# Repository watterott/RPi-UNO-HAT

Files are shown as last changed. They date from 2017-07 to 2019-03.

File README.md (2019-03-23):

# RPi-UNO-HAT
Raspberry Pi to Arduino/Genuino Shield Bridge.

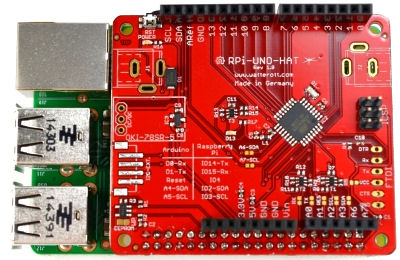
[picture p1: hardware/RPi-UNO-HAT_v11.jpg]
RPi-UNO-HAT


* Microchip ATmega328P with Arduino compatible Bootloader (optiboot)
* Raspberry Pi connected via I2C and UART (to the AVR through level-shifter)
* AVR-Programming via Raspberry Pi possible
* [Raspberry Pi HAT](https://github.com/raspberrypi/hats) compatible (40 pin connector)
* Shield connectors with Uno R3 layout
* Additional 3.3V LDO voltage regulator for Shields
* Optional 7-36V power input for Raspberry Pi and RPi-UNO-HAT (Murata OKI-78SR-5)
* Open-Source and released under the [Creative Commons Attribution Share-Alike License](https://creativecommons.org/licenses/by-sa/4.0/).
* **[Documentation on learn.watterott.com](https://learn.watterott.com)**

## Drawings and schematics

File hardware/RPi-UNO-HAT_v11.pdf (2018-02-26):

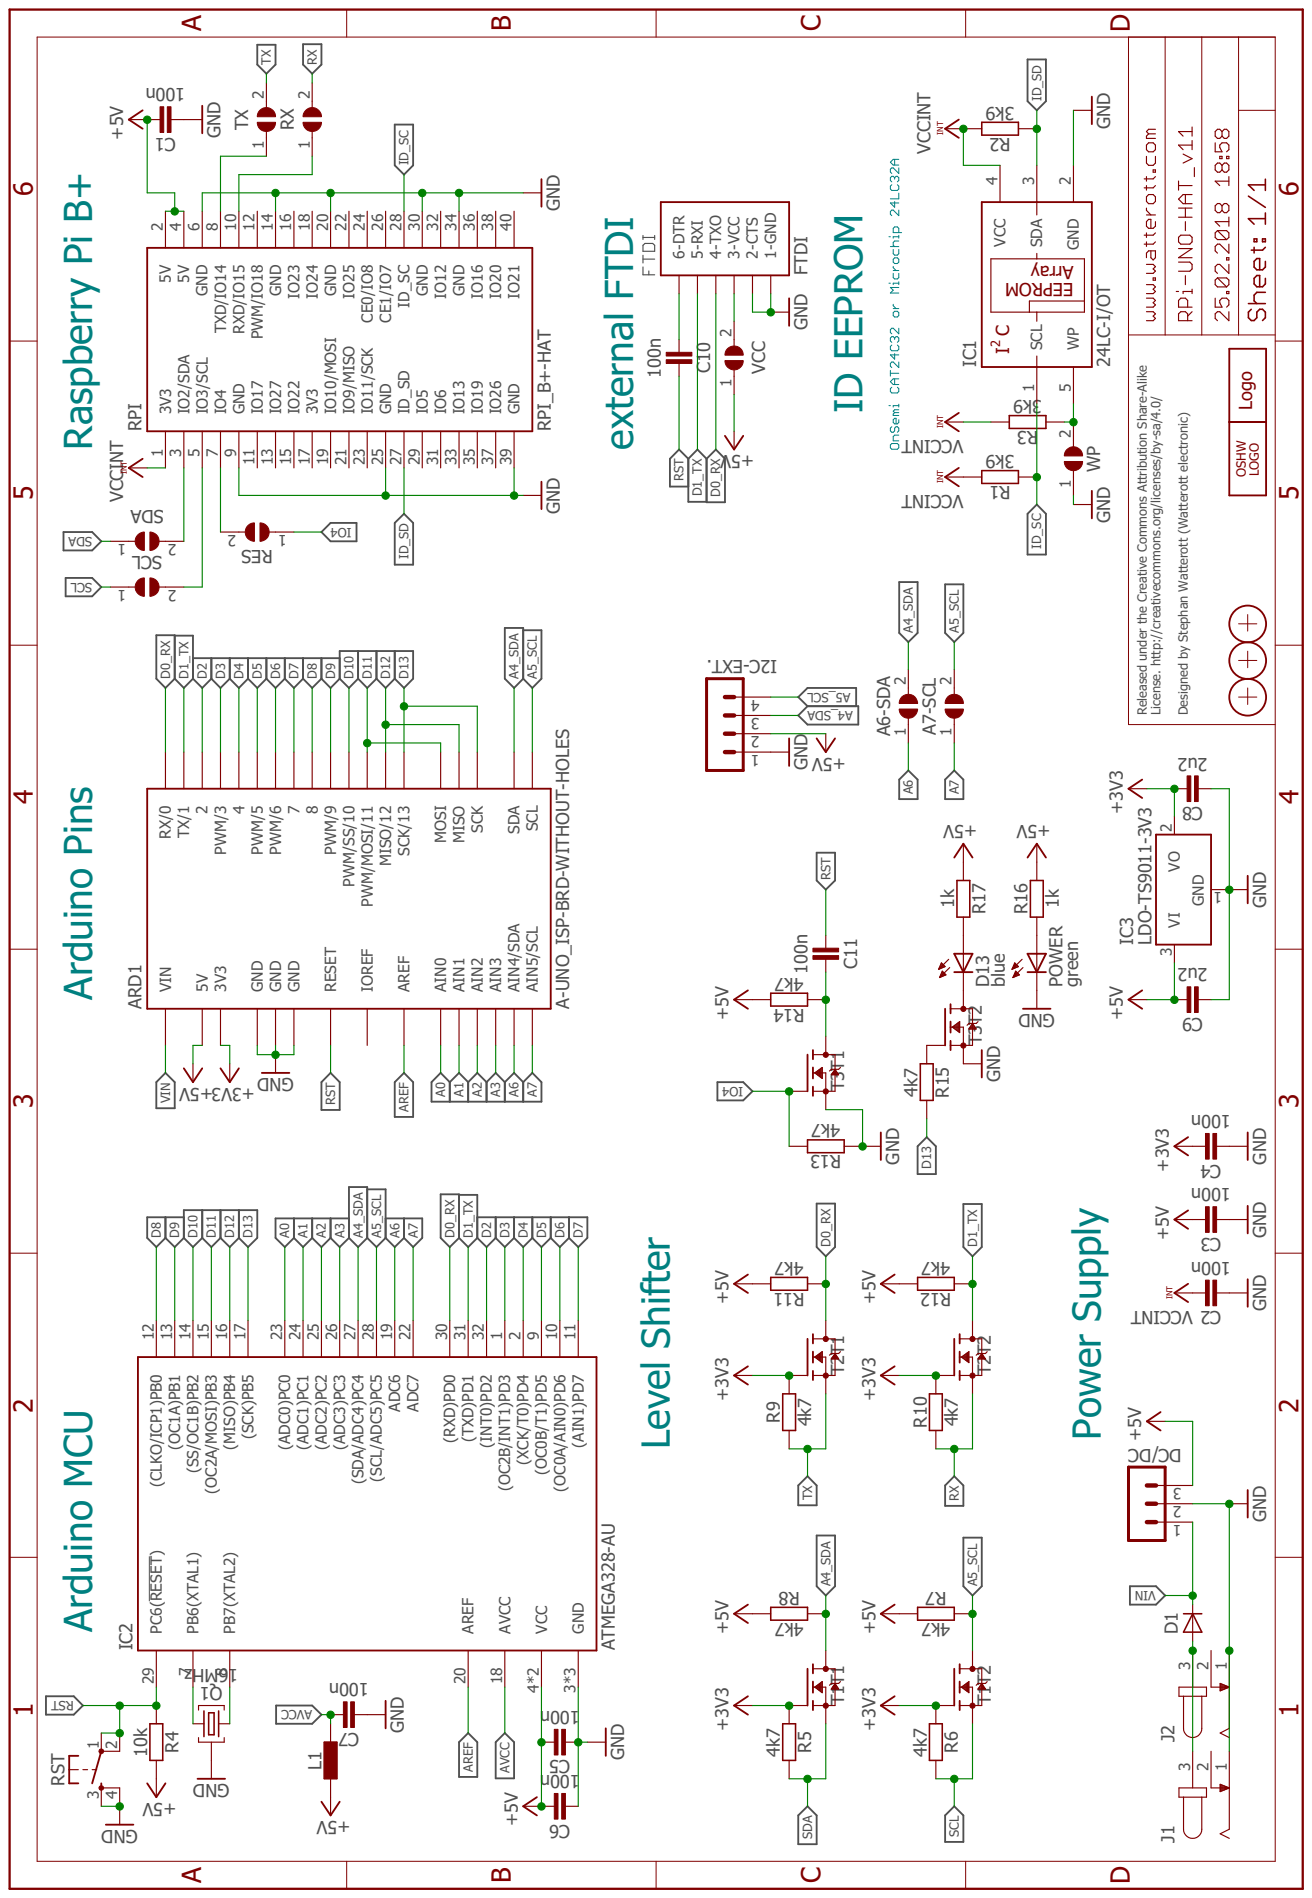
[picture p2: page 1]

Released under the Creative Commons Attribution Share-Alike

License. http://creativecommons.org/licenses/by-sa/4.0/ Designed by Stephan Watterott (Watterott electronic)

8 PWM/9 PWM/SS/10 PWM/MOSI/11 MISO/12 SCK/13 AIN1 AIN2 AIN3 AIN4/SDA

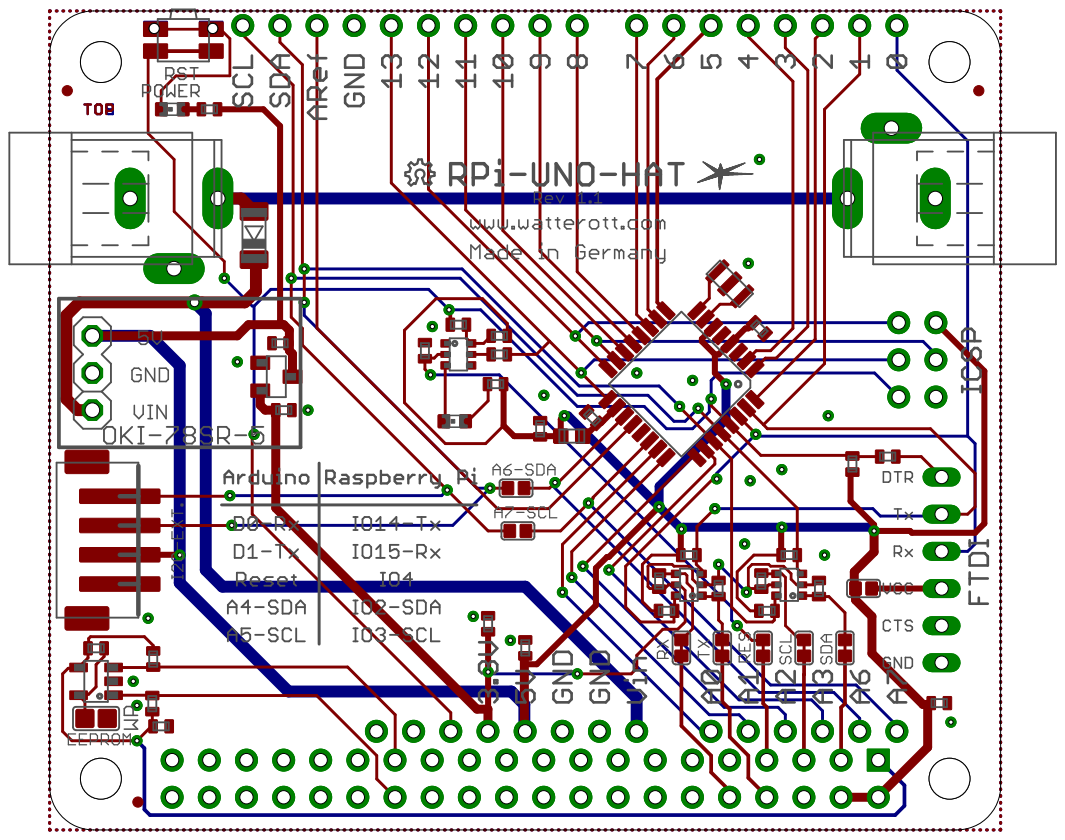
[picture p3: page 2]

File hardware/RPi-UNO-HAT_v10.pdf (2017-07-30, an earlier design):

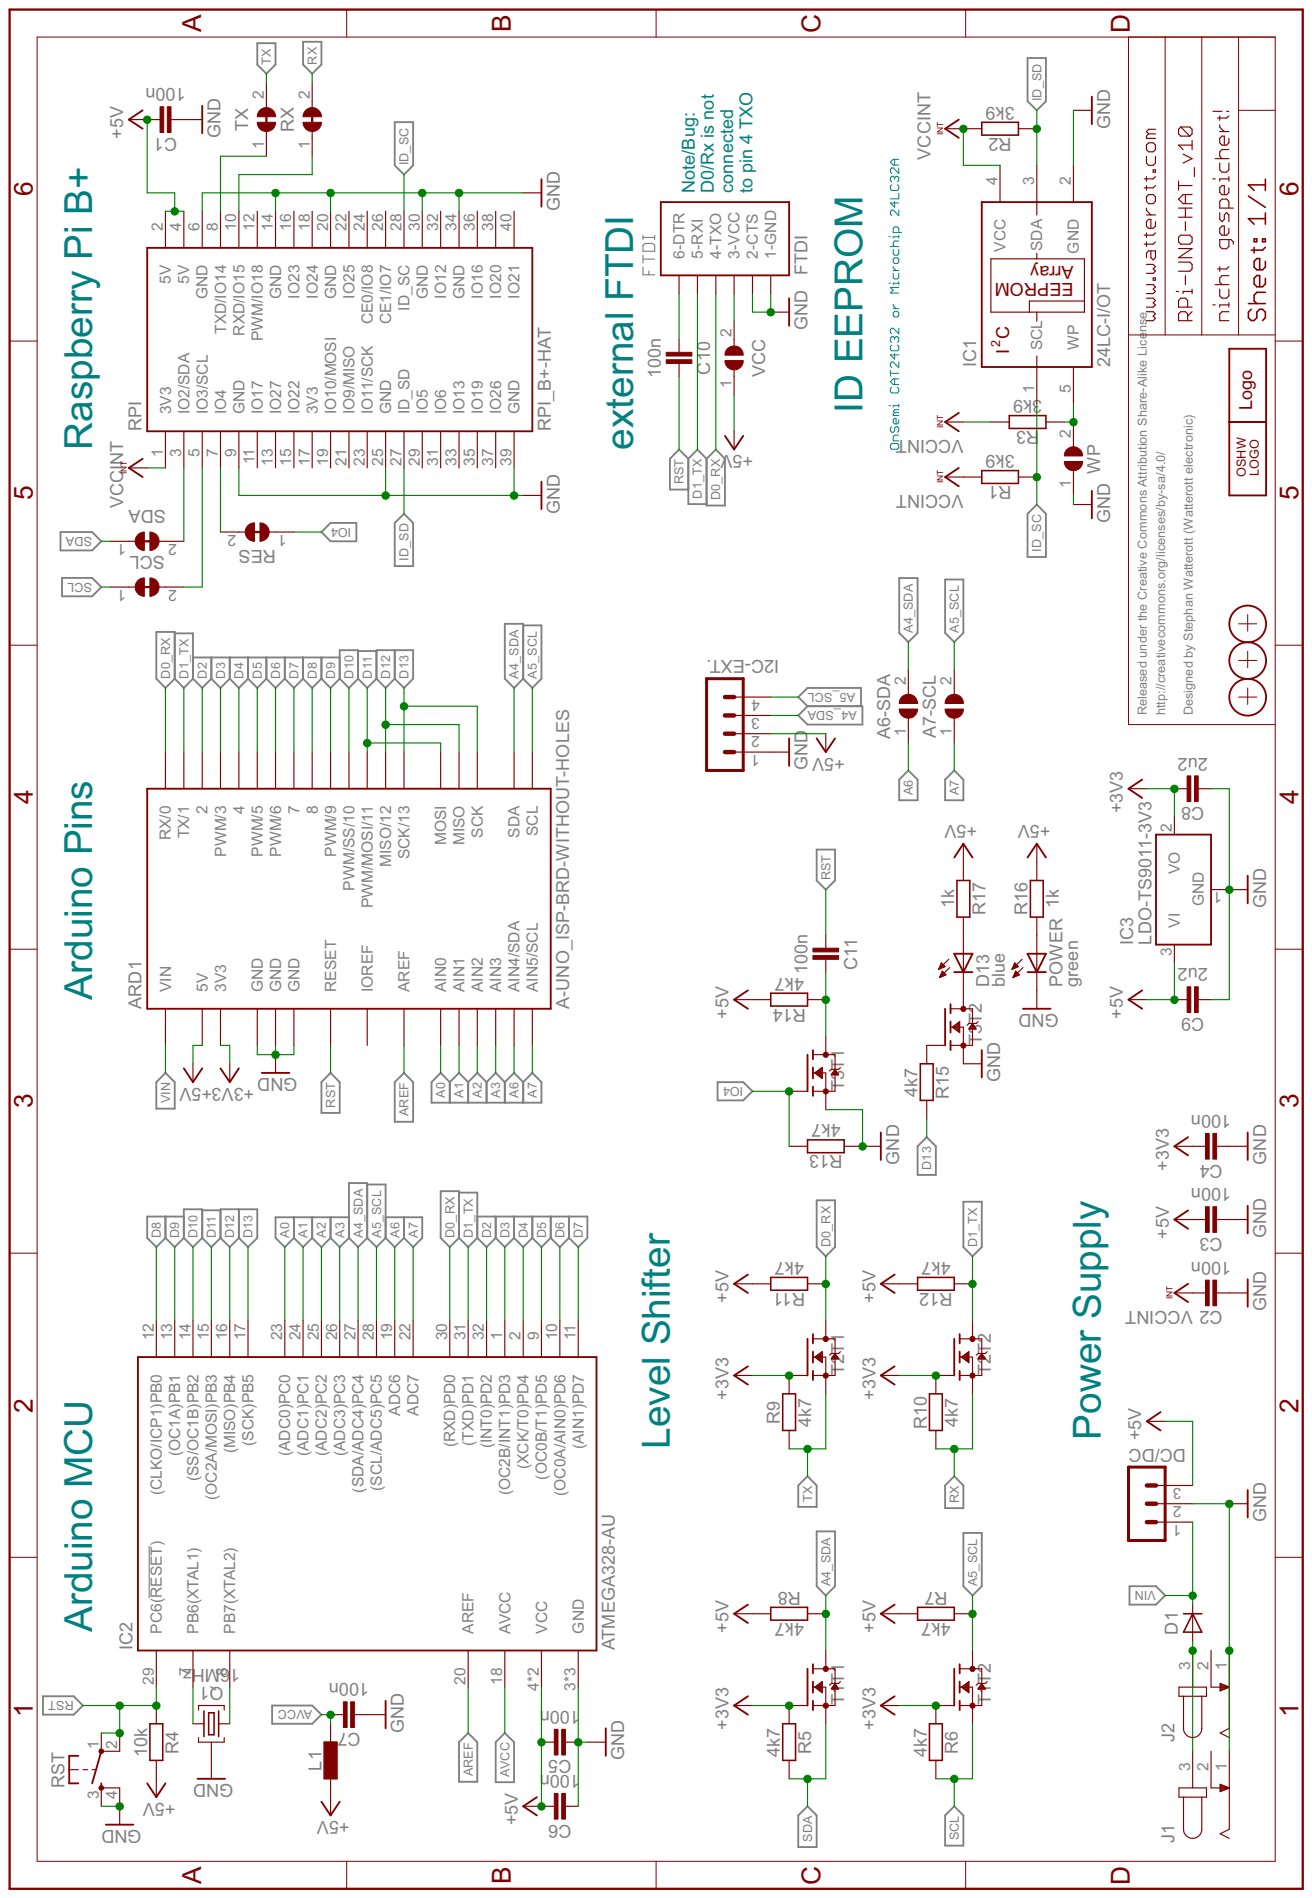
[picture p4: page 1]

DI Note/Bug: D0/Rx is not connected

Released under the Creative Commons Attribution Share-Alike License

http://creativecommons.org/licenses/by-sa/4.0/ Designed by Stephan Watterott (Watterott electronic)

GND GND GND MOSI MISO

8 PWM/9 PWM/SS/10 PWM/MOSI/11 MISO/12 SCK/13 AIN1 AIN2 AIN3 AIN4/SDA

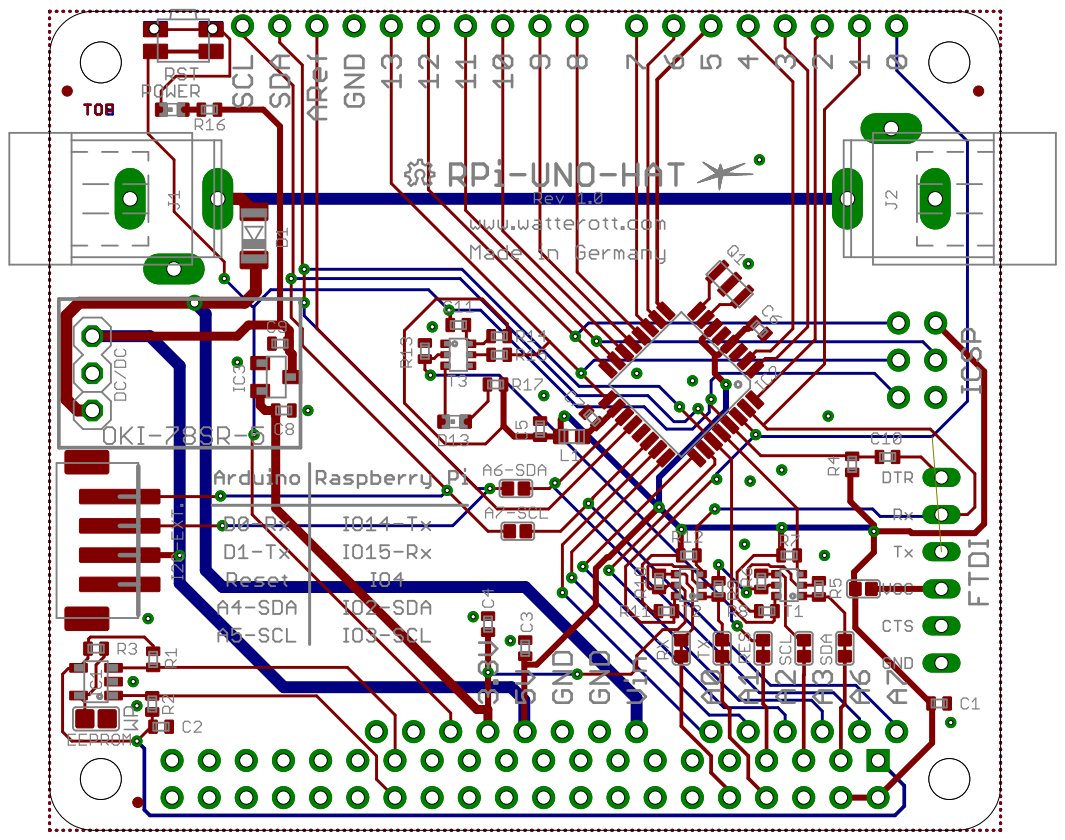
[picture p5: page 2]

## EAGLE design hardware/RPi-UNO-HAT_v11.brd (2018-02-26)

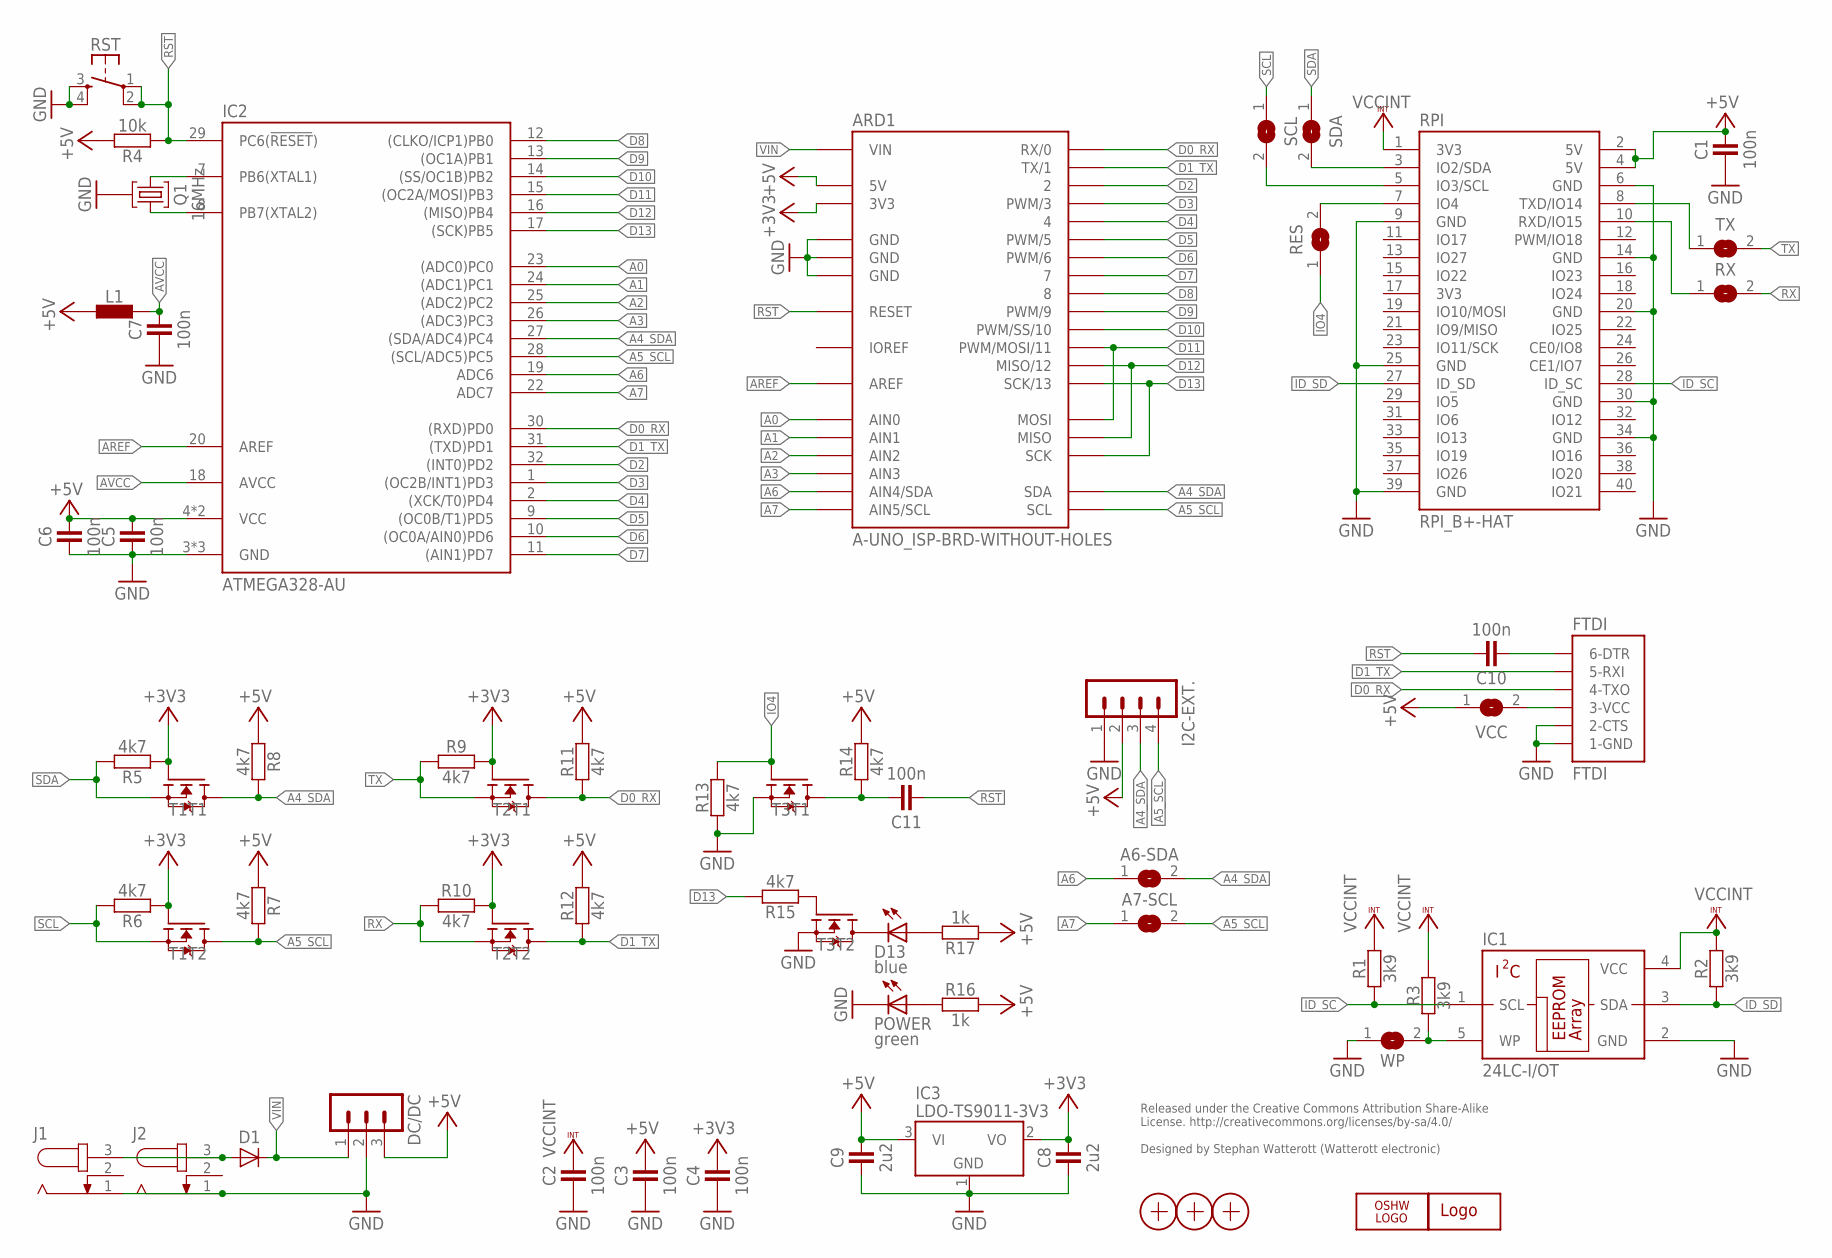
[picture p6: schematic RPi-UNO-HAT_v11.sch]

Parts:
A6-SDA, A7-SCL: JUMPER2-0402-NC; JUMPER2-0402_NC
ARD1: A-UNO_ISP-BRD-WITHOUT-HOLES; A-UNO-ISP_CON-WITHOUT-HOLES
C1, C2, C3, C4, C5, C6, C7, C10, C11: 100n; C0402
C8, C9: 2u2; C0402
D1: DIODE-SOD80; SOD80
D13: blue; C0603
DC/DC: MA03-1
FTDI: FTDI
I2C-EXT.: JST_PH_4B4B-PH-SM4-TB; JST_B4B-PH-SM4-TB
IC1: 24LC-I/OT; SOT23-5
IC2: ATMEGA328-AU; TQFP32
IC3: LDO-TS9011-3V3; SOT23
J1, J2: DC-JACK
L1: INDUCTOR-0603; C0603
LOGO1: LOGO-S_PLACE_S; SPARK_TPLACE_S
LOGO2: OSHW_LOGOX0070; OSHW_6X70
POWER: green; C0603
Q1: 16MHz; CRYSTAL_32X13
R1, R2, R3: 3k9; C0402
R4: 10k; C0402
R5, R6, R7, R8, R9, R10, R11, R12, R13, R14, R15: 4k7; C0402
R16, R17: 1k; C0402
RES: JUMPER2-0402-NC; JUMPER2-0402_NC
RPI: RPI_B+-HAT; RPI-B+HAT
RST: SW-TACTILE-PTS840P; SW_PTS840P
RX: JUMPER2-0402-NC; JUMPER2-0402_NC
SCL: JUMPER2-0402-NC; JUMPER2-0402_NC
SDA: JUMPER2-0402-NC; JUMPER2-0402_NC
T1, T2, T3: BSS138PS; SOT363
TX: JUMPER2-0402-NC; JUMPER2-0402_NC
VCC: JUMPER2-0402-NC; JUMPER2-0402_NC
WP: JUMPER2-0603-NC; JUMPER2-0603_NC
X1, X2, X3: PASSER-07; PASSER_07MM

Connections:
+3V3: ARD1.3V3, C4.2, C8.2, IC3.2 (VO), R5.1, R6.1, R9.2, R10.2, T1.2 (G), T1.5 (G), T2.2 (G), T2.5 (G)
+5V: ARD1.5V, ARD1.VCC (5V), C1.2, C3.2, C5.2, C6.2, C9.2, DC/DC.3, I2C-EXT..2, IC2.4 (VCC), IC2.6 (VCC), IC3.3 (VI), L1.1, R4.2, R7.1, R8.1, R11.2, R12.2, R14.2, R16.2, R17.1, RPI.2 (5V), RPI.4 (5V), VCC.1
A0: ARD1.A0 (AIN0), IC2.23 ((ADC0)PC0)
A1: ARD1.A1 (AIN1), IC2.24 ((ADC1)PC1)
A2: ARD1.A2 (AIN2), IC2.25 ((ADC2)PC2)
A3: ARD1.A3 (AIN3), IC2.26 ((ADC3)PC3)
A4_SDA: A6-SDA.2, ARD1.SDA, I2C-EXT..3, IC2.27 ((SDA/ADC4)PC4), R8.2, T1.6 (D)
A5_SCL: A7-SCL.2, ARD1.SCL, I2C-EXT..4, IC2.28 ((SCL/ADC5)PC5), R7.2, T1.3 (D)
A6: A6-SDA.1, ARD1.A4 (AIN4/SDA), IC2.19 (ADC6)
A7: A7-SCL.1, ARD1.A5 (AIN5/SCL), IC2.22 (ADC7)
AREF: ARD1.AREF, IC2.20 (AREF)
AVCC: C7.2, IC2.18 (AVCC), L1.2
D0_RX: ARD1.0 (RX/0), FTDI.4-TX (4-TXO), IC2.30 ((RXD)PD0), R11.1, T2.6 (D)
D0_RX1: C11.2, R14.1, T3.6 (D)
D1_TX: ARD1.1 (TX/1), FTDI.5-RX (5-RXI), IC2.31 ((TXD)PD1), R12.1, T2.3 (D)
D2: ARD1.2, IC2.32 ((INT0)PD2)
D3: ARD1.3 (PWM/3), IC2.1 ((OC2B/INT1)PD3)
D4: ARD1.4, IC2.2 ((XCK/T0)PD4)
D5: ARD1.5 (PWM/5), IC2.9 ((OC0B/T1)PD5)
D6: ARD1.6 (PWM/6), IC2.10 ((OC0A/AIN0)PD6)
D7: ARD1.7, IC2.11 ((AIN1)PD7)
D8: ARD1.8, IC2.12 ((CLKO/ICP1)PB0)
D9: ARD1.9 (PWM/9), IC2.13 ((OC1A)PB1)
D10: ARD1.10 (PWM/SS/10), IC2.14 ((SS/OC1B)PB2)
D11: ARD1.11 (PWM/MOSI/11), ARD1.MOSI, IC2.15 ((OC2A/MOSI)PB3)
D12: ARD1.12 (MISO/12), ARD1.MISO, IC2.16 ((MISO)PB4)
D13: ARD1.13 (SCK/13), ARD1.SCK, IC2.17 ((SCK)PB5), R15.2
GND: ARD1.GND@1 (GND), ARD1.GND@2 (GND), ARD1.GND@3 (GND), ARD1.GND@4 (GND), C1.1, C2.1, C3.1, C4.1, C5.1, C6.1, C7.1, C8.1, C9.1, DC/DC.2, FTDI.1-GND, FTDI.2-CTS, I2C-EXT..1, IC1.2 (GND), IC2.3 (GND), IC2.5 (GND), IC2.21 (GND), IC3.1 (GND), J1.1, J2.1, POWER.C, Q1.GND, R13.1, RPI.6 (GND), RPI.9 (GND), RPI.14 (GND), RPI.20 (GND), RPI.25 (GND), RPI.30 (GND), RPI.34 (GND), RPI.39 (GND), RST.3 (S1), RST.4 (S2), T3.1 (S), T3.4 (S), WP.1
ID_SC: IC1.1 (SCL), R1.1, RPI.28 (ID_SC)
ID_SD: IC1.3 (SDA), R2.1, RPI.27 (ID_SD)
IO4: R13.2, RES.1, T3.2 (G)
IOREF: ARD1.IOREF
unnamed: IC2.8 (PB7(XTAL2)), Q1.1
unnamed: IC2.7 (PB6(XTAL1)), Q1.2
unnamed: D1.A, J1.3, J2.3
unnamed: C10.1, FTDI.6-DTR
unnamed: RPI.8 (TXD/IO14), TX.1
unnamed: RPI.10 (RXD/IO15), RX.1
unnamed: RES.2, RPI.7 (IO4)
unnamed: FTDI.3-VCC, VCC.2
unnamed: RPI.5 (IO3/SCL), SCL.2
unnamed: RPI.3 (IO2/SDA), SDA.2
unnamed: R15.1, T3.5 (G)
unnamed: POWER.A, R16.1
unnamed: D13.A, R17.2
unnamed: D13.C, T3.3 (D)
RST: ARD1.RST (RESET), ARD1.RST2 (RESET), C10.2, C11.1, IC2.29 (PC6(!RESET!)), R4.1, RST.1, RST.2
RX: R10.1, RX.2, T2.4 (S)
SCL: R6.2, SCL.1, T1.4 (S)
SDA: R5.2, SDA.1, T1.1 (S)
TX: R9.1, T2.1 (S), TX.2
VCCINT: C2.2, IC1.4 (VCC), R1.2, R2.2, R3.2, RPI.1 (3V3)
VIN: ARD1.VIN, D1.C, DC/DC.1
WP: IC1.5 (WP), R3.1, WP.2

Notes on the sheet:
Released under the Creative Commons Attribution Share-Alike License. http://creativecommons.org/licenses/by-sa/4.0/ Designed by Stephan Watterott (Watterott electronic)

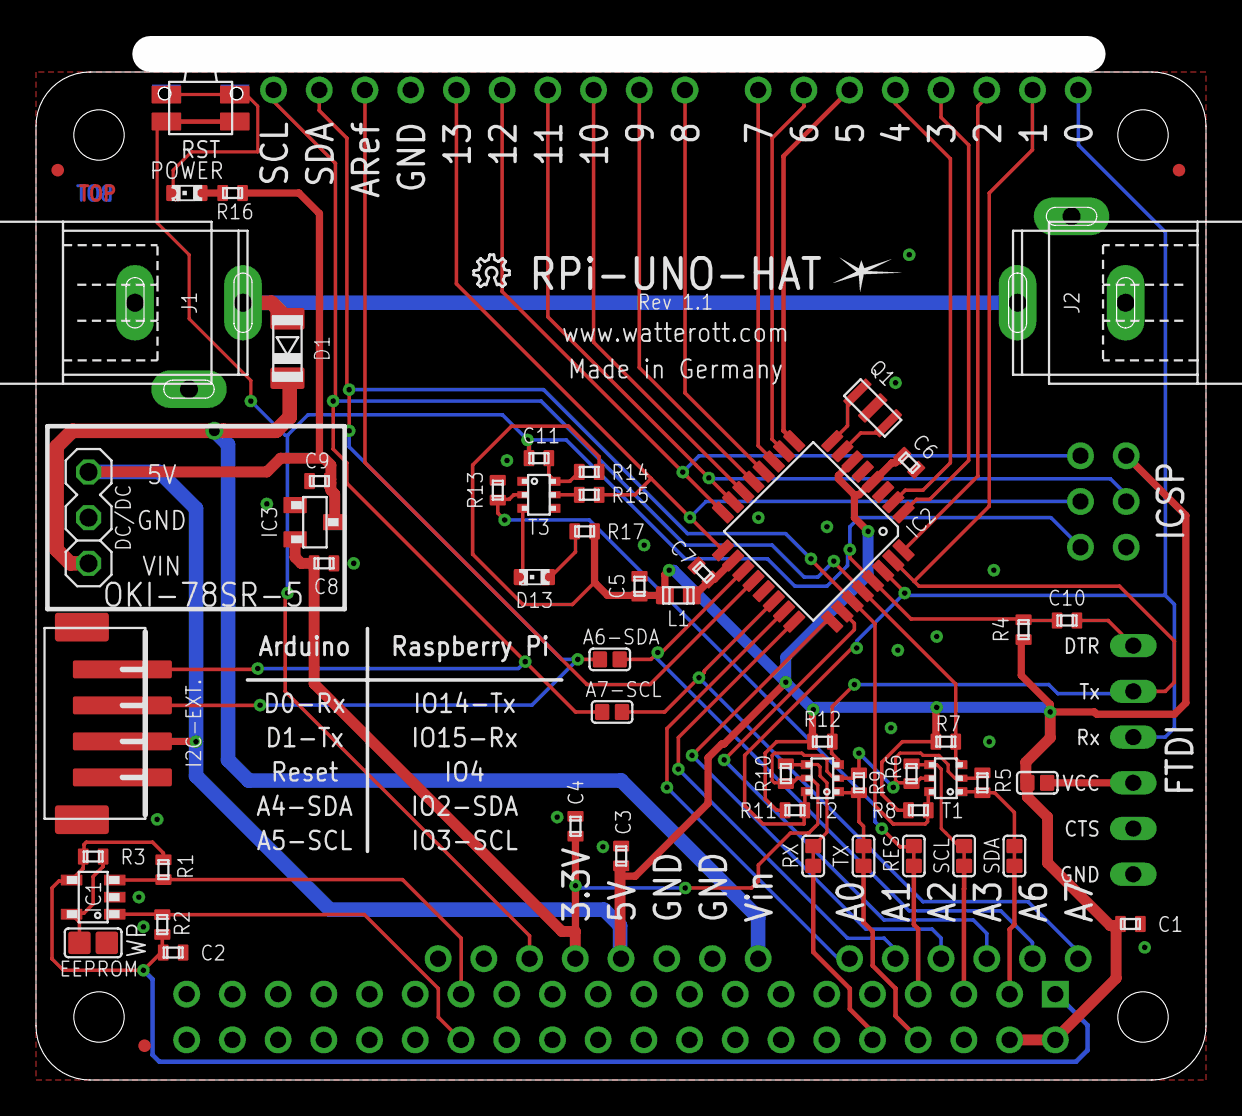
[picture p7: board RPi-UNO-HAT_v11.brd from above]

Board: 2 copper layers, 65.0 x 57.0 mm, 61 parts (0 on the bottom side), 53 nets.

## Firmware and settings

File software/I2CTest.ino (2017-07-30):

#include <Wire.h> 

#define ADDRESS 0x30

void setup() 
{
  pinMode(13, OUTPUT);     // set pin 13 as output (LED connected)
  digitalWrite(13, LOW);   // set pin 13 to low (0V)

  Wire.begin(ADDRESS);     // join I2C bus with respective address
  Wire.onReceive(receive); // receive data function
  Wire.onRequest(request); // send data function
} 

void loop() 
{
  // do nothing
} 

void receive(int numBytes) // function that runs when data is received
{
  unsigned char c;

  while(Wire.available())
  { 
    c = Wire.read();
    if(c == 0x00)      // LED off, if byte equals 0
    {
      digitalWrite(13, LOW);
    }
    else if(c == 0x01) // LED on, if byte equals 1
    {
      digitalWrite(13, HIGH);
    }
  }
}

void request() // function that runs when data is requested
{
  Wire.write(0xAA); // send 0xAA
}
